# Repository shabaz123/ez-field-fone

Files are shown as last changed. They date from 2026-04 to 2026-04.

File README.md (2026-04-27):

# E-Z Field Fone

This repository contains a project for an intercom / field phone. The design uses discrete components throughout.  

The design includes:
- KiCad 10 Schematic and PCB files
- KiCad 10 SPICE Simulation Workbook
- Gerber files for fabrication  
- PDF schematic export and PCB screenshots for easy viewing without KiCad

# How It Works

The audio input (from on-board mic, or via a handset/earpiece jack socket) is amplified, then sent over bell wire to the remote unit. The signal on the bell wire is fed into a difference amplifier, in order to subtract the local audio. The difference output is fed into a power amplifier. The user can signal a call alert by applying a DC voltage onto the bell wire. There is an amplifier that is sensitive to DC, and the output can be used to light an indicator or sound a buzzer alert.

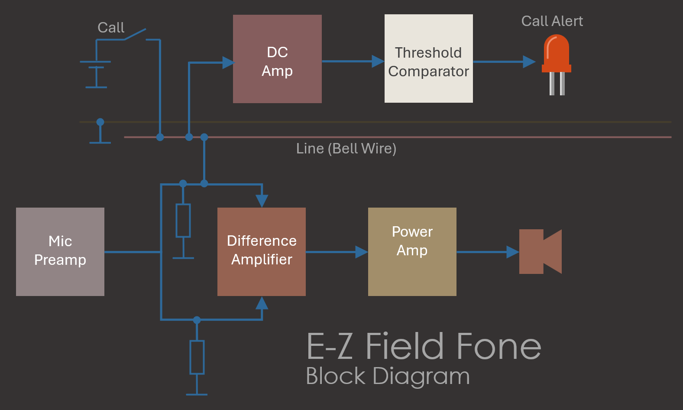
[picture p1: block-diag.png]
Block Diagram


# Printed Circuit Board Overview

The design is split up into two separate printed circuit boards (PCBs). One PCB contains the microphone amplifier (Mic Booard) and the other contains everything else (Main Board). You'll need a mic board, and a main board, for each unit. The two boards are designed to fit into at least a couple of different enclosures. 

# Enclosures

The circuit boards will comfortably fit inside a Hammond 1559E enclosure (170 x 85 x 34 mm) along with a large 60 mm diameter (66 x 66 mm square) 8 ohm speaker such as Pui AS06608PS-R and a PP3 battery. 

If you prefer to omit the speaker and use an external handset, then a smaller Hammond 1593X (140 x 66 x 28 mm) can be used. 

If you wish to use any other enclosure, the PCB dimensions are:

Mic Board: 59 x 32.5 mm

Main Board: 59 x 55 mm

# Mic Board

The mic board uses a preamplifier designed by M. Kellett.

- **Gain:** ~45 dB  
- **Bandwidth (-3 dB):** ~100 Hz to 7 kHz (approximate)

## Schematic

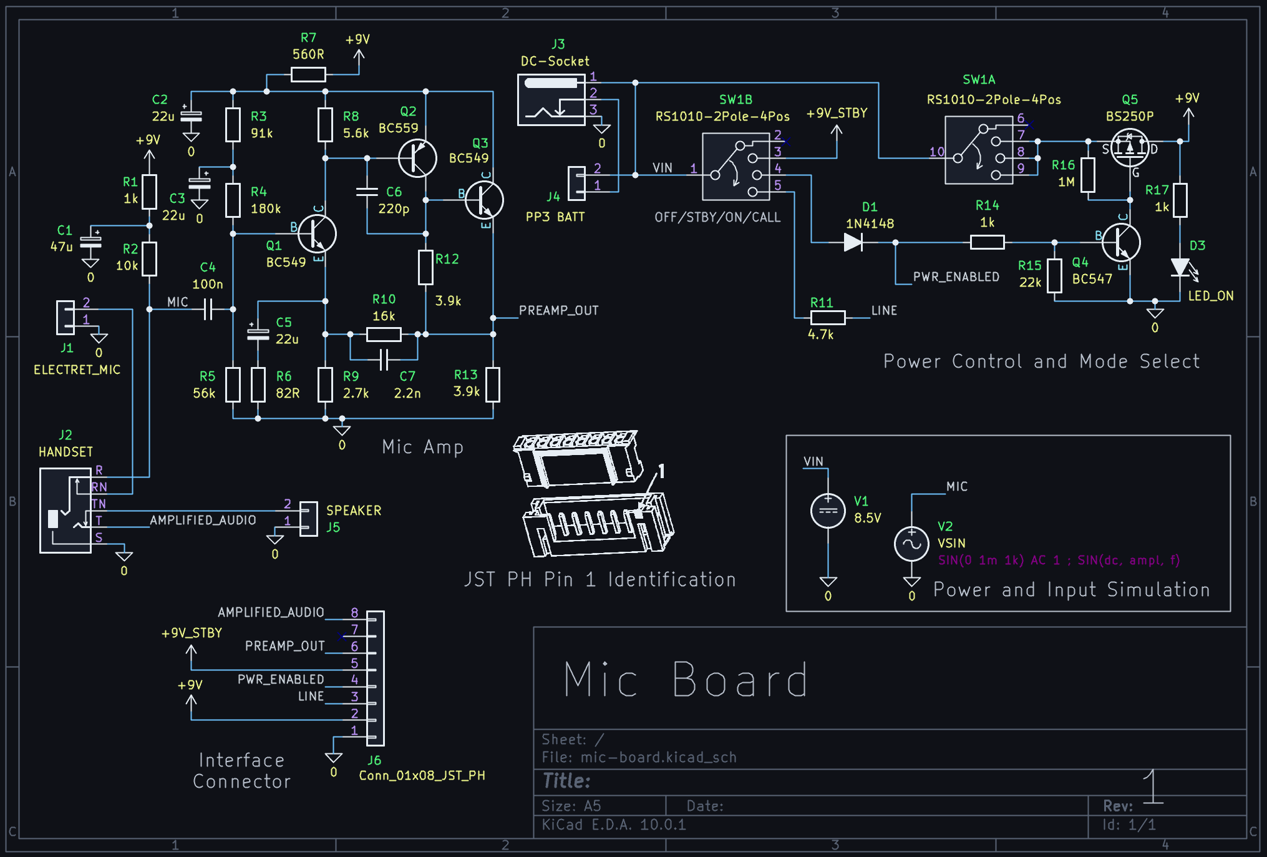
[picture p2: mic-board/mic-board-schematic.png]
Mic Board Schematic


## Board Connections

Two sets of soldered connections need to be made to the Mic Board; the microphone element, and the speaker. Also, an 8-pin connector is used to attach the Mic Board to the Main Board.

### Electret Mic Element

The Mic Board has a 2-pin location for soldering an electret mic element using screened cable

### Speaker

There is a 2-pin location for soldering an 8-ohm speaker

### Interfacing Connector

An 8-pin connector is used to connect a cable between the Mic Board and the Main Board. 

A ready-made JST PH 8-way "opposite direction", also known as "reverse direction" cable can be used (available from AliExpress). The opposite/reverse direction means that when laid flat, opposite sides of the connector are seen from one end to the other (this means that pin 1 of the both connectors are attached to each other, and pin 2 of both connectors are attached to each other, and so on; in contrast, a "same direction" cable has pin 1 on one connector wired to pin 8 of the other connector, and pin 2 to pin 7, and so on). 

Double-check you have the correct cable; do NOT purchase a "same direction" cable!

If you're using the larger Hammond enclosure, the cable length needs to ideally be 15cm (available from a few AliExpress stores) or alternatively 20cm (which more AliExpress stores offer). 

If you're using the smaller Hammond enclosure, a 10cm length cable should reach, but you'll need to measure it or try it out.

## 3.5 mm Audio Jack Pinout

If you wish to plug in an external mic and speaker/eaerphone, use the 3.5 mm 3-pin socket. Connections are:

- Tip: Audio Out, connect this to any earphone or headphones, or to an 8-ohm speaker
- Ring: Microphone, connect this to an electret mic element (the Mic Board PCB supplies a low voltage to power the element)
- Shield: Ground

## PCB Top

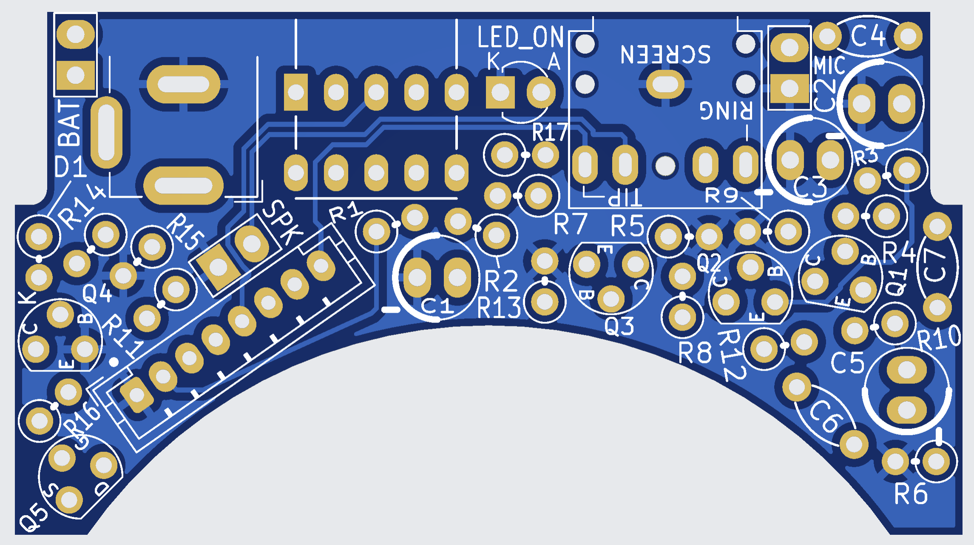
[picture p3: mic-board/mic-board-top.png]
Mic Board Top


## PCB Underside

Note that one wire link needs to be made on the underside; it is labeled on the board.

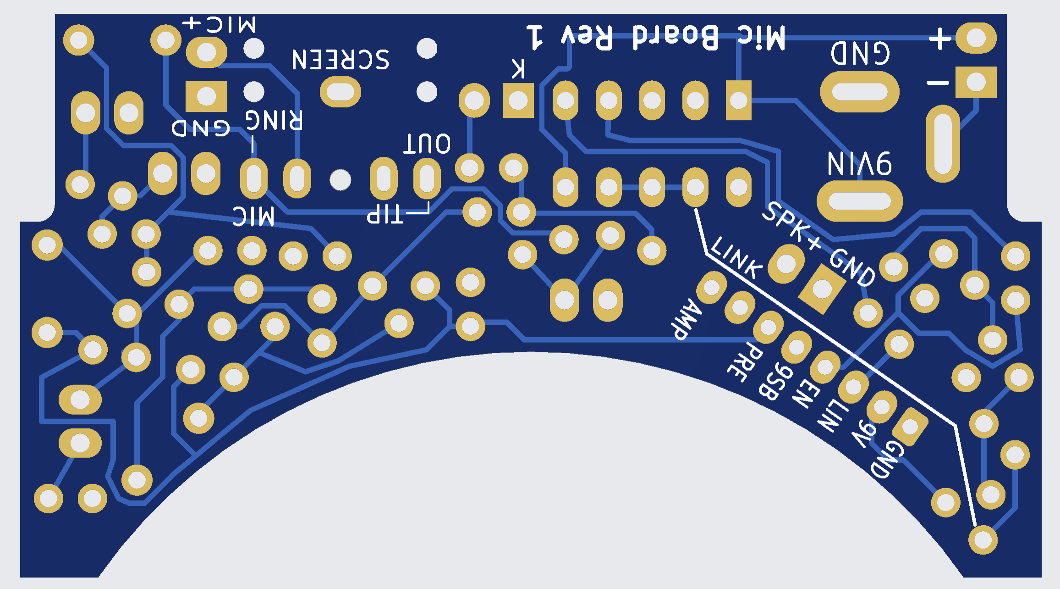
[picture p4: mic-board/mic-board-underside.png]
Mic Board Top


## PCB Render

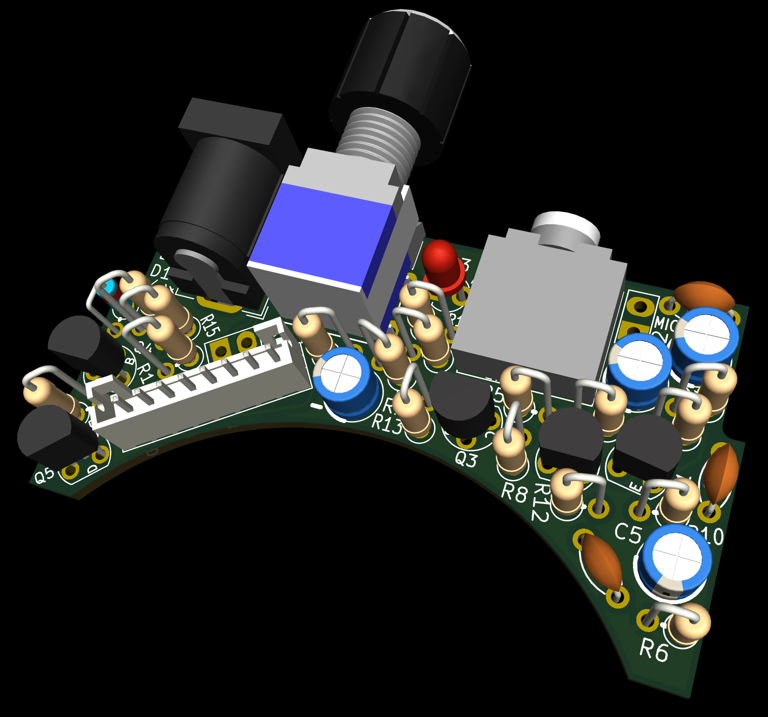
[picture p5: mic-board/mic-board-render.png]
Mic Board Render


## Enclosure Cutouts

The Mic Board requires the following holes to be drilled in the enclosure:

- DC barrel socket
- Rotary switch (4-position, for Off/Standby/On/Call)
- Power ON LED indicator
- 3.5 mm audio socket (for external mic and external earphone/speaker)
- Hole for electret mic element

---

# Main Board

The main board includes a 280mW audio amplifier designed by M. Kellett. 

## Schematic

Note: Resistor R35 is specified to be 630 ohm, this is a hard-to-find value, it may be replaced by 620 ohm in series with 10 ohm (on the PCB, solder 620 ohm and 10 ohm vertically, and connect them at the top with solder).

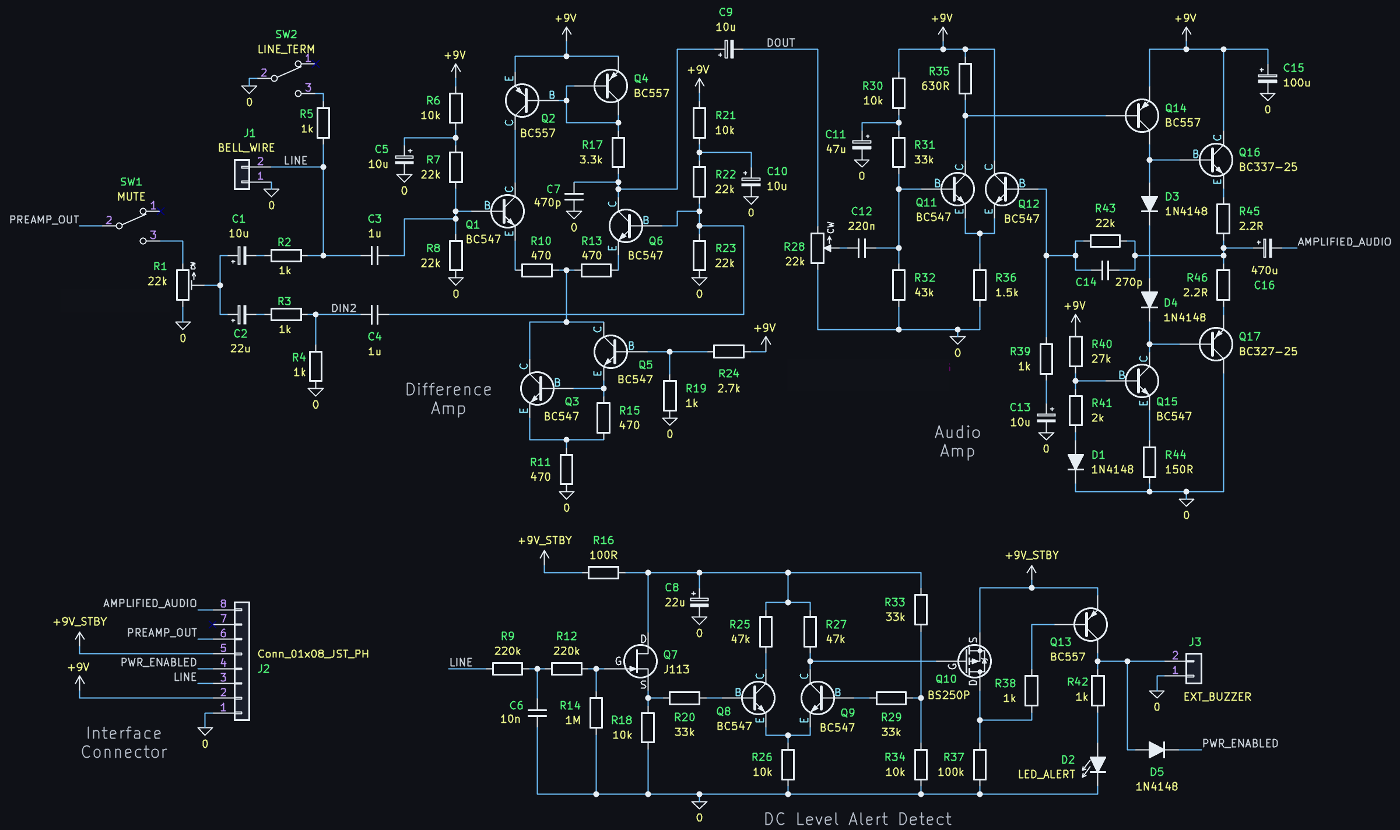
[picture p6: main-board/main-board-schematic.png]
Main Board Schematic


## Board Connections

The only off-board connection from the Main Board is the 8-way connection that interfaces to the Mic Board. See the Mic Board notes earlier, for an explanation of the required cable (8-way JST PH cable, "opposite/reverse direction", i.e. identical pin mapping, pin 1 to pin 1, and pin 2 to pin 2, and so on).

## PCB Top

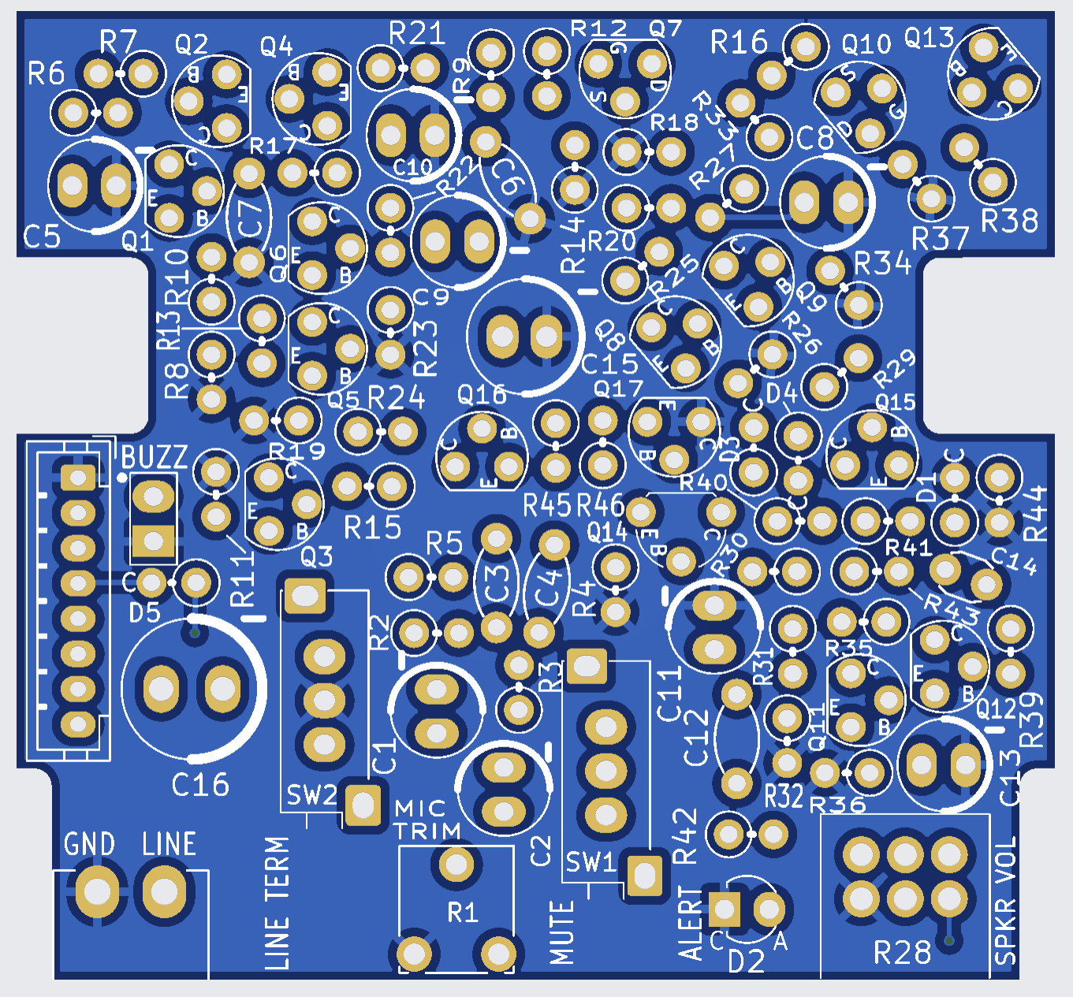
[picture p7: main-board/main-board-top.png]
Main Board Top


## PCB Underside

Note that there are two wire links that need to be soldered on the board underside. The connections are labeled A and B on the circuit board (connect A to A, and connect B to B).

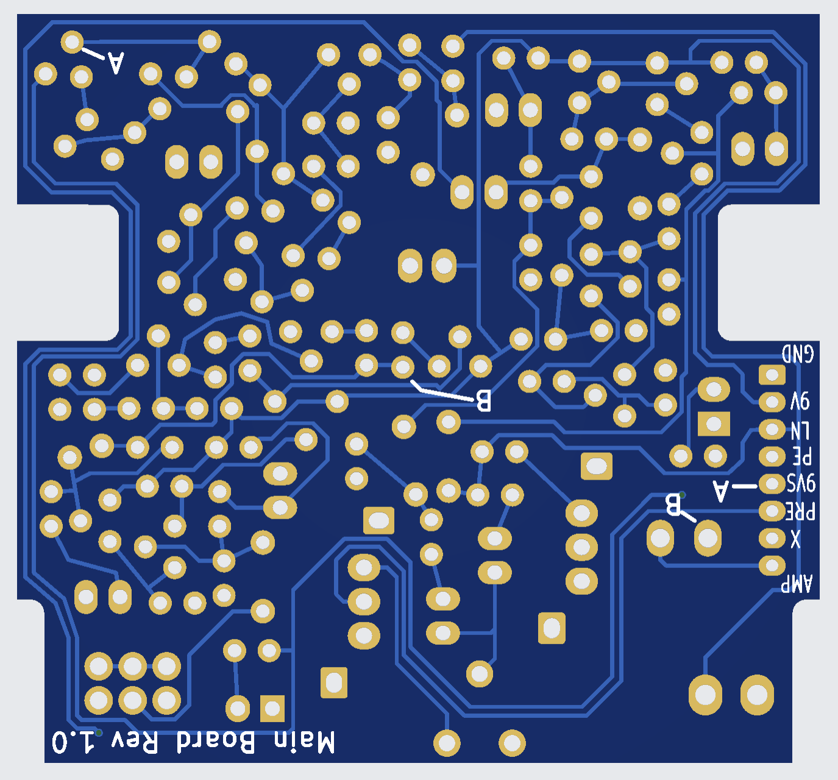
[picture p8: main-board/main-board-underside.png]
Main Board Top


## PCB Render

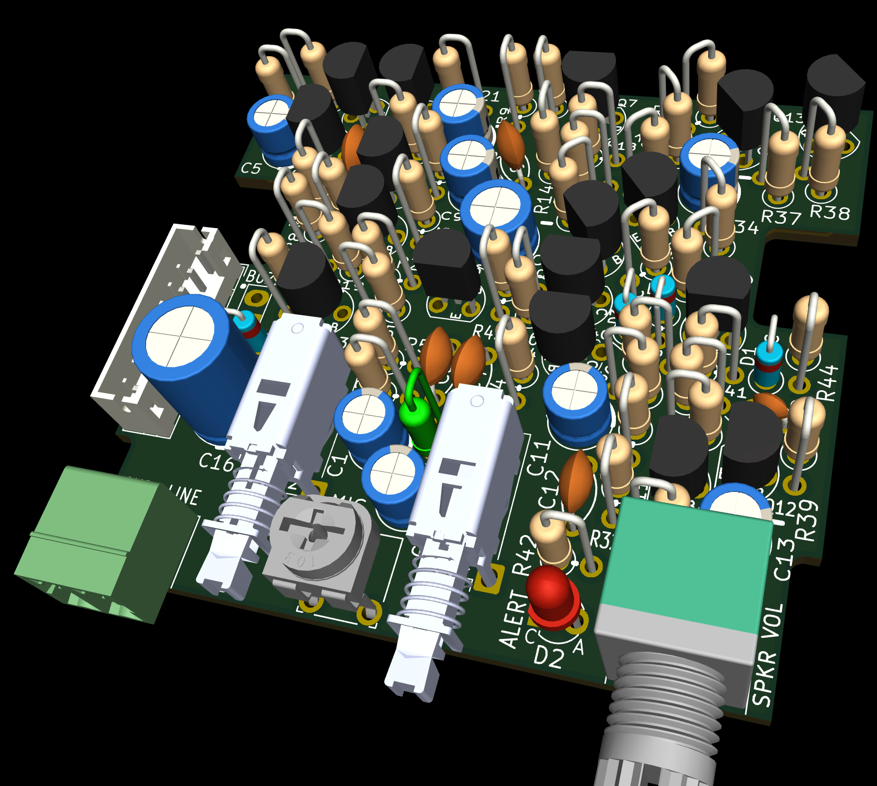
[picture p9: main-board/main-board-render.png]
Main Board Render


## Enclosure Cutouts

The Main Board requires the following holes to be drilled in the enclosure:

- An approximately 9 x 7.5 mm rectangular hole for a 3.81 mm pitch 2-way plug-in terminal block, used for attaching bell wire
- Two approximately 6 mm diameter holes, one for the mute button, and one for the recessed line termination button (the bell wire needs terminating at one end)
- 7.5 mm dia hole for the volume control potentiometer
- Hole for the call alert LED indicator
- Hole for an audio buzzer (if a buzzer is fitted) for audible call alerts

---

## Notes

All components are easy to source. 

For the input power, use a 9V PP3 battery, or use the 9V DC barrel socket (center positive).

The potentiometer can be ALPS RK097 series (available from AliExpress), it has pins at 2.5 mm pitch, and a body width of 10 mm.

The rotary switch is type RS1010 4-way (available from AliExpress)

The push switches can be either PS-12E05, or PN12 series by CK/Littelfuse

For the trimmer resistor, RM065 series will fit the PCB

The line connector (for attaching the bell wire) is a 2-way 3.81 mm pitch terminal block, there are many generic options. One example is WJ15EDGRC-3.81-02P-14-00A (which mates with part code WJ15EDGK-3.81-02P-14-00A

---

# Parts Lists

## Mic Board Parts List

| Reference  | Qty | Value | Description |
| --- | --- | --- | --- |
| C1 | 1 | 47u | Electrolytic Capacitor 5mm dia |
| C2,C3,C5 | 3 | 22u | Electrolytic Capacitor 5mm dia |
| C4 | 1 | 100n | Ceramic Capacitor 5mm pitch |
| C6 | 1 | 220p | Ceramic Capacitor 5mm pitch |
| C7 | 1 | 2.2n | Ceramic Capacitor 5mm pitch |
| D1 | 1 | 1N4148 | Small Signal Diode |
| D3 | 1 | LED_ON | LED 3mm dia |
| J1 | 1 | ELECTRET_MIC | Electret Mic Element |
| J2 | 1 | HANDSET | SJ1-3525N 3.5mm jack CUI |
| J3 | 1 | DC-Socket | 2.1/5.5mm DC Jack Socket |
| J4 | 1 | PP3 BATT | Battery Clip PP3 |
| J5 | 1 | SPEAKER | AS06608PS-R 8-ohm  60mm dia (66 x 66mm) |
| J6 | 1 | B8B-PH-K-S | JST PH Header 8-way Vertical |
| Q1,Q3 | 2 | BC549 | NPN TO-92 Low Noise BJT |
| Q2 | 1 | BC559 | PNP TO-92 Low Noise BJT |
| Q4 | 1 | BC547 | NPN TO-92 BJT |
| Q5 | 1 | BS250P | P-ch MOSFET TO-92 |
| R1,R14,R17 | 3 | 1k | Resistor 1/8W or 1/4W |
| R2 | 1 | 10k | Resistor 1/8W or 1/4W |
| R3 | 1 | 91k | Resistor 1/8W or 1/4W |
| R4 | 1 | 180k | Resistor 1/8W or 1/4W |
| R5 | 1 | 56k | Resistor 1/8W or 1/4W |
| R6 | 1 | 82R | Resistor 1/8W or 1/4W |
| R7 | 1 | 560R | Resistor 1/8W or 1/4W |
| R8 | 1 | 5.6k | Resistor 1/8W or 1/4W |
| R9 | 1 | 2.7k | Resistor 1/8W or 1/4W |
| R10 | 1 | 16k | Resistor 1/8W or 1/4W |
| R11 | 1 | 4.7k | Resistor 1/8W or 1/4W |
| R12,R13 | 2 | 3.9k | Resistor 1/8W or 1/4W |
| R15 | 1 | 22k | Resistor 1/8W or 1/4W |
| R16 | 1 | 1M | Resistor 1/8W or 1/4W |
| SW1 | 1 | RS1010-2Pole-4Pos | 2P4T Rotary Switch |
| n/a | 1 | JST PH 15cm Cable | 8way Opposite/Reverse Direction cable |
| n/a | 1 | Knob 6mm Knurled  | 15mm dia outer, flower inner hole 6mm |

## Main Board Parts List
| Reference | Qty | Value | Description |
| --- | --- | --- | --- |
| C1,C5,C9,C10,C13 | 5 | 10u | Electrolytic Capacitor 5mm dia |
| C2,C8 | 2 | 22u | Electrolytic Capacitor 5mm dia |
| C3,C4 | 2 | 1u | Ceramic Capacitor 5mm pitch |
| C6 | 1 | 10n | Ceramic Capacitor 5mm pitch |
| C7 | 1 | 470p | Ceramic Capacitor 5mm pitch |
| C11 | 1 | 47u | Electrolytic Capacitor 5mm dia |
| C12 | 1 | 220n | Ceramic Capacitor 5mm pitch |
| C14 | 1 | 270p | Ceramic Capacitor 2.5mm pitch |
| C15 | 1 | 100u | Electrolytic Capacitor 6.3mm dia |
| C16 | 1 | 470u | Electrolytic Capacitor 8mm dia |
| D1,D3,D4,D5 | 4 | 1N4148 | Small Signal Diode |
| D2 | 1 | LED_ALERT | LED 3mm dia |
| J1 | 1 | Term Block 3.81mm | 2-way WJ15EDGRC-3.81-02P-14-00A |
| J2 | 1 | B8B-PH-K-S | JST PH Header 8-way Vertical |
| J3 | 1 | EXT_BUZZER | 9V Buzzer (optional) |
| Q1,Q3,Q5,Q6,Q8,Q9,Q11,Q12,Q15 | 9 | BC547 | NPN TO-92 BJT |
| Q2,Q4,Q13,Q14 | 4 | BC557 | PNP TO-92 BJT |
| Q7 | 1 | J113 | N-ch JFET TO-92 |
| Q10 | 1 | BS250P | P-ch MOSFET TO-92 |
| Q16 | 1 | BC337-25 | NPN TO-92 Power BJT |
| Q17 | 1 | BC327-25 | PNP TO-92 Power BJT |
| R1 | 1 | 22k | RM065 Trimmer Potentiometer |
| R2,R3,R4,R5,R19,R38,R39,R42 | 8 | 1k | Resistor 1/8W or 1/4W |
| R6,R18,R21,R26,R30,R34 | 6 | 10k | Resistor 1/8W or 1/4W |
| R7,R8,R22,R23,R43 | 5 | 22k | Resistor 1/8W or 1/4W |
| R9,R12 | 2 | 220k | Resistor 1/8W or 1/4W |
| R10,R11,R13,R15 | 4 | 470R | Resistor 1/8W or 1/4W |
| R14 | 1 | 1M | Resistor 1/8W or 1/4W |
| R16 | 1 | 100R | Resistor 1/8W or 1/4W |
| R17 | 1 | 3.3k | Resistor 1/8W or 1/4W |
| R20,R29,R31,R33 | 4 | 33k | Resistor 1/8W or 1/4W |
| R24 | 1 | 2.7k | Resistor 1/8W or 1/4W |
| R25,R27 | 2 | 47k | Resistor 1/8W or 1/4W |
| R28 | 1 | 22k | Resistor 1/8W or 1/4W |
| R32 | 1 | 43k | Resistor 1/8W or 1/4W |
| R35 | 1 | 630R (620R+10R) | Resistor 1/8W or 1/4W |
| R36 | 1 | 1.5k | Resistor 1/8W or 1/4W |
| R37 | 1 | 100k | Resistor 1/8W or 1/4W |
| R40 | 1 | 27k | Resistor 1/8W or 1/4W |
| R41 | 1 | 2k | Resistor 1/8W or 1/4W |
| R44 | 1 | 150R | Resistor 1/8W or 1/4W |
| R45,R46 | 2 | 2.2R | Resistor 1/4W |
| SW1 | 1 | PS-12E05 | SPDT Switch Latching PN12 |
| SW2 | 1 | PS-12E05 | SPDT Switch Latching PN12 |
| n/a | 1 | Plug 3.81mm | 2-way WJ15EDGK-3.81-02P-14-00A |
| n/a | 1 | Knob 6mm Knurled  | 15mm dia outer, flower inner hole 6mm |

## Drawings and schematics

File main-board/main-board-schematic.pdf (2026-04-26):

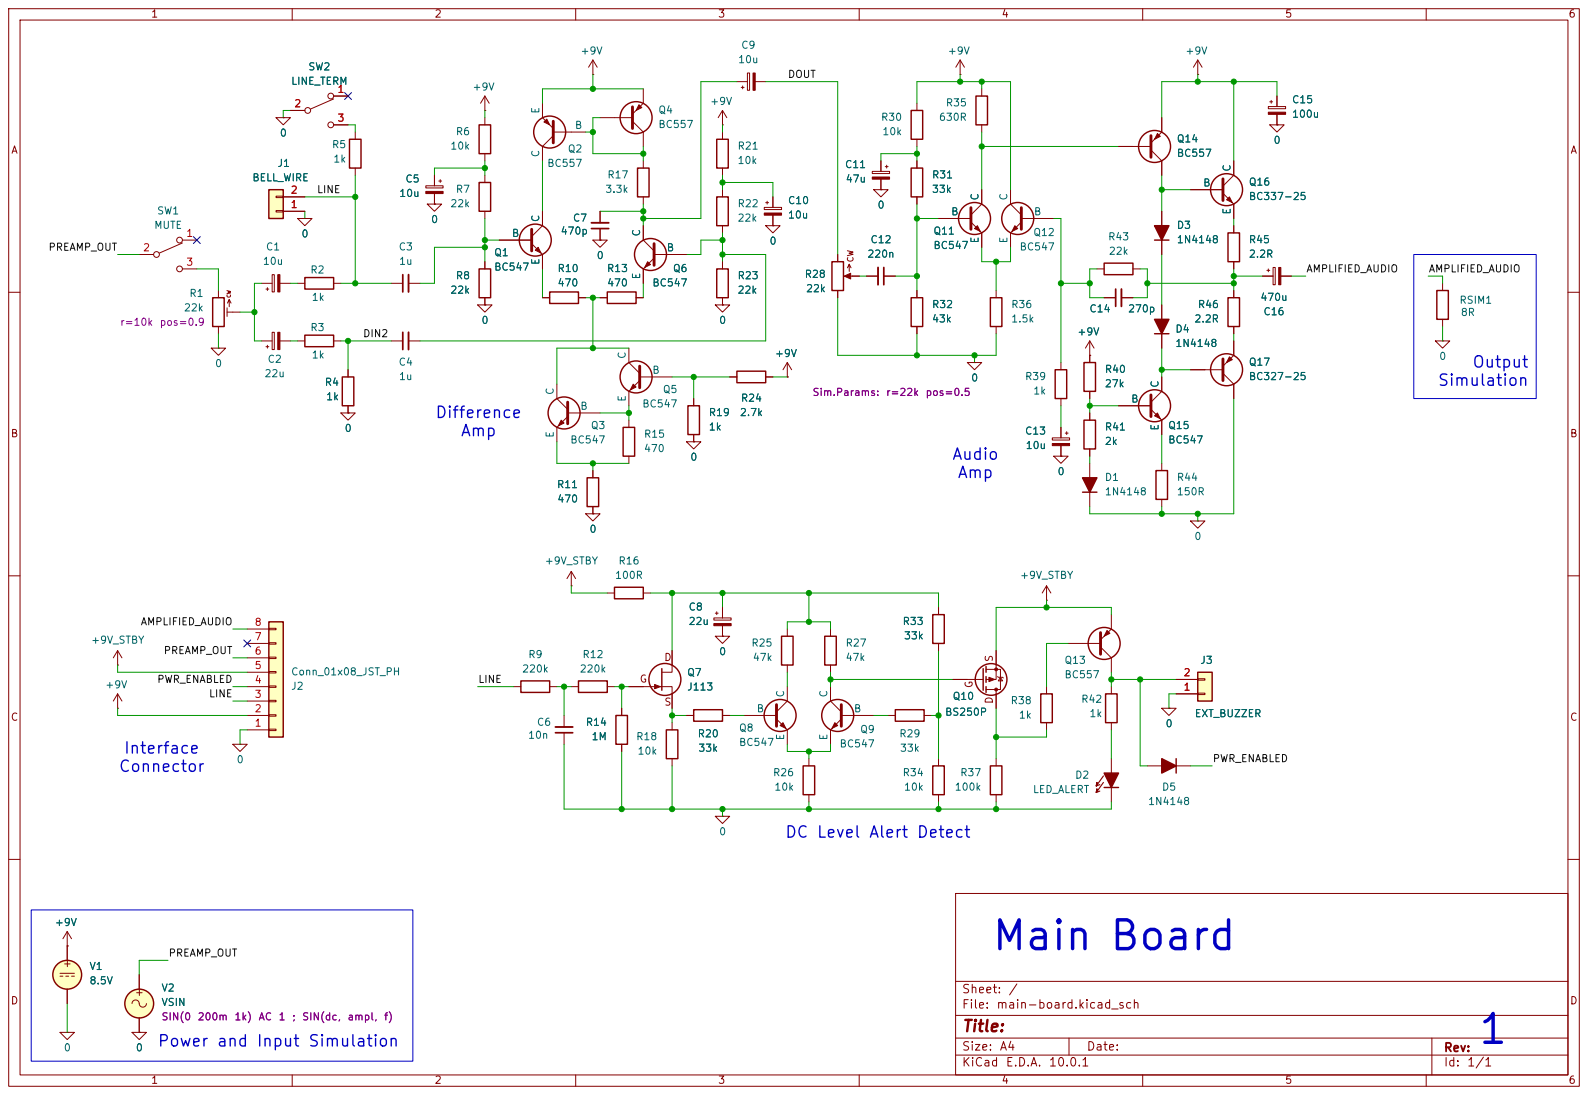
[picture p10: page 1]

AMPLIFIED_AUDIO Power and Input Simulation

DC Level Alert Detect

SIN(0 200m 1k) AC 1 ; SIN(dc, ampl, f) V1

Size: A4 | Rev:
KiCad E.D.A. 10.0.1 | Id: 1/1

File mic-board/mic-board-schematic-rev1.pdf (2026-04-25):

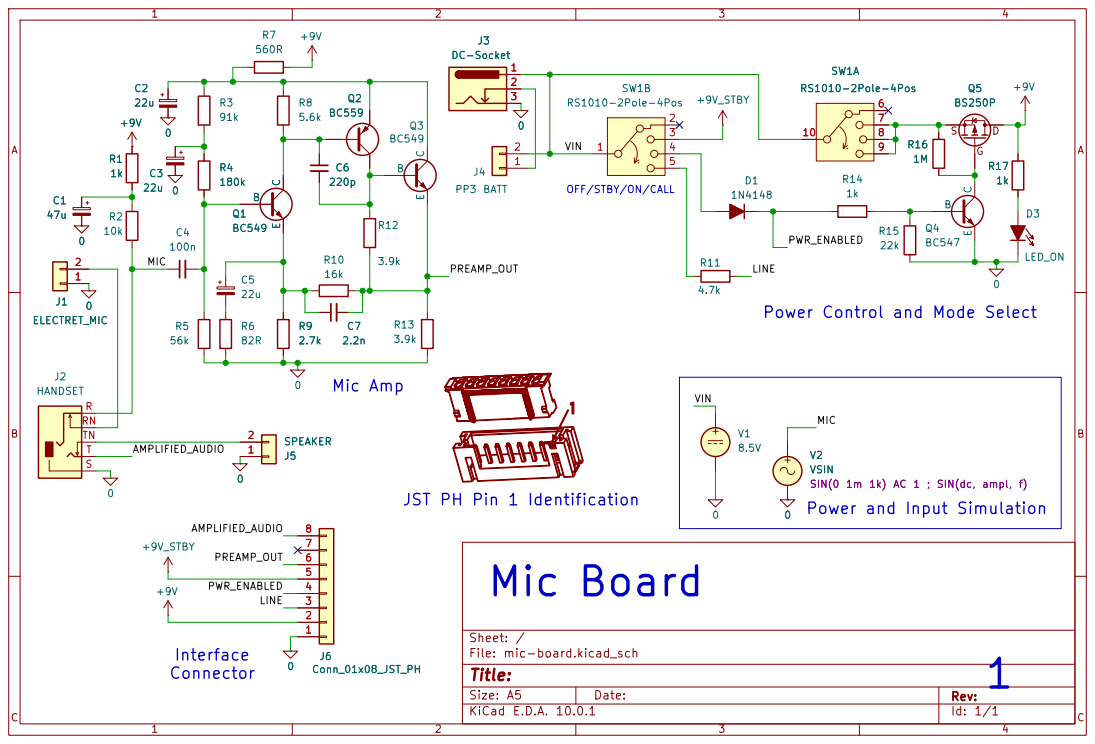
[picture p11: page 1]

Power Control and Mode Select SW1A RS1010-2Pole-4Pos 6

SIN(0 1m 1k) AC 1 ; SIN(dc, ampl, f) 0 Q1BC549 C

OFF/STBY/ON/CALL

VSIN
SIN(0 1m 1k) AC 1 ; SIN(dc, ampl, f) 0
Power and Input Simulation

JST PH Pin 1 Identification

Size: A5 | Rev: | C Date:
KiCad E.D.A. 10.0.1 | Id: 1/1

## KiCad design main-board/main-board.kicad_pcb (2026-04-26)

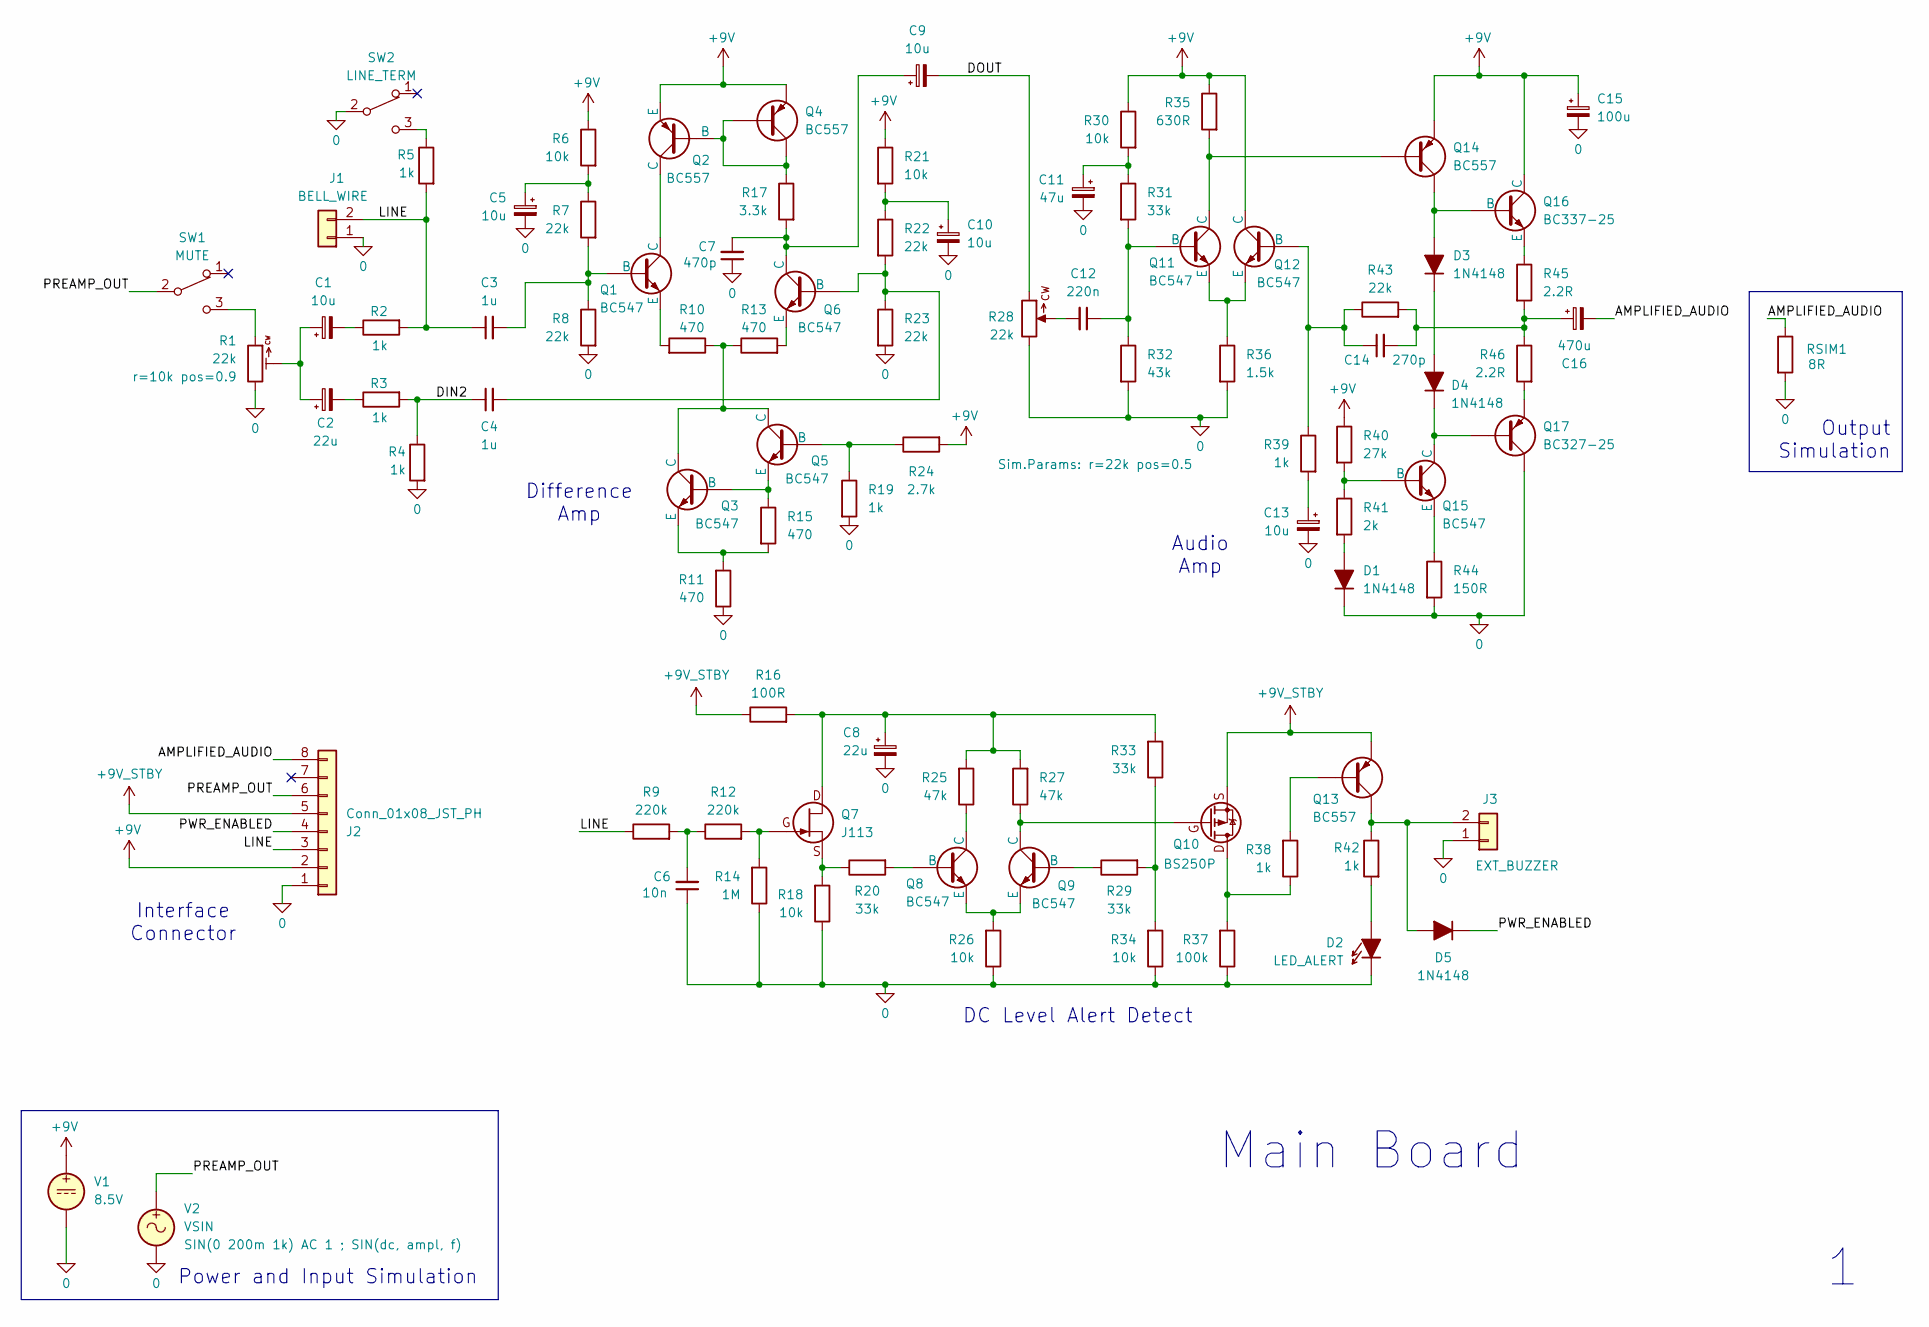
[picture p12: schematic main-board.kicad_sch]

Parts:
C1, C5, C9, C10, C13: 10u; CP_Radial_D5.0mm_P2.50mm
C2, C8: 22u; CP_Radial_D5.0mm_P2.50mm
C3, C4: 1u; C_Disc_T3.0mm_P5.0
C6: 10n; C_Disc_T3.0mm_P5.0
C7: 470p; C_Disc_T3.0mm_P5.0
C11: 47u; CP_Radial_D5.0mm_P2.50mm
C12: 220n; C_Disc_T3.0mm_P5.0
C14: 270p; C_Disc_T2.5mm_P2.5
C15: 100u; CP_Radial_D6.3mm_P2.50mm
C16: 470u; CP_Radial_D8mm_P3.5mm
D1, D3, D4, D5: 1N4148; D_DO-35_P2.54mm_Vertical_CathodeUp
D2: LED_ALERT; LED_3mm
J1: BELL_WIRE; TerminalBlock_RightAngle-2way-3.81mm
J2: Conn_01x08_JST_PH; JST_PH_Vertical_8way
J3: EXT_BUZZER; PinHeader_1x02_P2.54mm_Vertical
Q1, Q3, Q5, Q8, Q9, Q11, Q12, Q15: BC547; BJT_NPN_BC547_Compact
Q2, Q4, Q13: BC557; BJT_PNP_BC557_Compact
Q6: BC547; BJT_PNP_BC557_Compact
Q7: J113; J113_NCH_JFET_Compact
Q10: BS250P; MOSFET_BS250P_Compact
Q14: BC557; BJT_PNP_BC557_Compact2
Q16: BC337-25; BJT_NPN_BC547_Compact
Q17: BC327-25; BJT_PNP_BC557_Compact
R1: 22k; Potentiometer_Trimmer_RM065
R2, R3, R4, R5, R19, R38, R39, R42: 1k; R_Axial_L6.3mm_D2.5mm_P2.54mm_Vertical
R6, R18, R21, R26, R30, R34: 10k; R_Axial_L6.3mm_D2.5mm_P2.54mm_Vertical
R7, R8, R22, R23, R43: 22k; R_Axial_L6.3mm_D2.5mm_P2.54mm_Vertical
R9, R12: 220k; R_Axial_L6.3mm_D2.5mm_P2.54mm_Vertical
R10, R11, R13, R15: 470; R_Axial_L6.3mm_D2.5mm_P2.54mm_Vertical
R14: 1M; R_Axial_L6.3mm_D2.5mm_P2.54mm_Vertical
R16: 100R; R_Axial_L6.3mm_D2.5mm_P2.54mm_Vertical
R17: 3.3k; R_Axial_L6.3mm_D2.5mm_P2.54mm_Vertical
R20, R29, R31, R33: 33k; R_Axial_L6.3mm_D2.5mm_P2.54mm_Vertical
R24: 2.7k; R_Axial_L6.3mm_D2.5mm_P2.54mm_Vertical
R25, R27: 47k; R_Axial_L6.3mm_D2.5mm_P2.54mm_Vertical
R28: 22k; Potentiometer_RD701F
R32: 43k; R_Axial_L6.3mm_D2.5mm_P2.54mm_Vertical
R35: 630R; R_Axial_L6.3mm_D2.5mm_P2.54mm_Vertical
R36: 1.5k; R_Axial_L6.3mm_D2.5mm_P2.54mm_Vertical
R37: 100k; R_Axial_L6.3mm_D2.5mm_P2.54mm_Vertical
R40: 27k; R_Axial_L6.3mm_D2.5mm_P2.54mm_Vertical
R41: 2k; R_Axial_L6.3mm_D2.5mm_P2.54mm_Vertical
R44: 150R; R_Axial_L6.3mm_D2.5mm_P2.54mm_Vertical
R45, R46: 2.2R; R_Axial_L6.3mm_D2.5mm_P2.54mm_Vertical
RSIM1: 8R; R_Axial_L6.3mm_D2.5mm_P10.16mm_Horiz
SW1: MUTE; PS-12E05
SW2: LINE_TERM; PS-12E05
V1: 8.5V
V2: VSIN

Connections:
0: C5.2, C6.1, C7.1, C8.2, C10.2, C11.2, C13.2, C15.2, D1.1 (K), D2.1 (K), J1.1, J2.1, J3.1, Q17.1 (C), R1.1, R4.2, R8.2, R11.1, R14.1, R18.1, R19.2, R23.2, R26.1, R28.1, R32.2, R34.1, R36.2, R37.1, R44.2, RSIM1.2, SW2.2 (B), V1.2, V2.2
+9V: C15.1, J2.2, Q2.3 (E), Q4.3 (E), Q12.1 (C), Q14.3 (E), Q16.1 (C), R6.1, R21.1, R24.2, R30.1, R35.1, R40.1, V1.1
+9V_STBY: J2.5, Q10.1 (S), Q13.3 (E), R16.1
/AMPLIFIED_AUDIO: C16.2, J2.8, RSIM1.1
/DIN2: C4.1, R3.2, R4.1
/DOUT: C9.2, R28.3
/LINE: C3.1, J1.2, J2.3, R2.2, R5.2, R9.1
/PREAMP_OUT: J2.6, SW1.2 (B), V2.1
/PWR_ENABLED: D5.1 (K), J2.4
unnamed: C1.1, C2.1, R1.2
unnamed: C1.2, R2.1
unnamed: C2.2, R3.1
unnamed: C5.1, R6.2, R7.1
unnamed: C6.2, R9.2, R12.1
unnamed: C10.1, R21.2, R22.1
unnamed: C11.1, R30.2, R31.1
unnamed: C12.2, R28.2
unnamed: C13.1, R39.2
unnamed: C14.2, C16.1, R43.2, R45.2, R46.1
unnamed: D1.2 (A), R41.2
unnamed: D2.2 (A), R42.2
unnamed: D3.2 (A), Q14.1 (C), Q16.2 (B)
unnamed: D3.1 (K), D4.2 (A)
unnamed: D4.1 (K), Q15.1 (C), Q17.2 (B)
unnamed: D5.2 (A), J3.2, Q13.1 (C), R42.1
unnamed: C3.2, Q1.2 (B), R7.2, R8.1
unnamed: Q1.1 (C), Q2.1 (C)
unnamed: Q1.3 (E), R10.2
unnamed: Q2.2 (B), Q4.1 (C), Q4.2 (B), R17.1
unnamed: Q3.2 (B), Q5.3 (E), R15.1
unnamed: Q3.1 (C), Q5.1 (C), R10.1, R13.1
unnamed: Q3.3 (E), R11.2, R15.2
unnamed: Q5.2 (B), R19.1, R24.1
unnamed: C4.2, Q6.2 (B), R22.2, R23.1
unnamed: C7.2, C9.1, Q6.1 (C), R17.2
unnamed: Q6.3 (E), R13.2
unnamed: C8.1, Q7.1 (D), R16.2, R25.2, R27.2, R33.2
unnamed: Q7.3 (G), R12.2, R14.2
unnamed: Q7.2 (S), R18.2, R20.1
unnamed: Q8.2 (B), R20.2
unnamed: Q8.1 (C), R25.1
unnamed: Q8.3 (E), Q9.3 (E), R26.2
unnamed: Q9.2 (B), R29.1
unnamed: Q10.3 (D), R37.2, R38.1
unnamed: Q9.1 (C), Q10.2 (G), R27.1
unnamed: C12.1, Q11.2 (B), R31.2, R32.1
unnamed: Q11.1 (C), Q14.2 (B), R35.2
unnamed: Q11.3 (E), Q12.3 (E), R36.1
unnamed: C14.1, Q12.2 (B), R39.1, R43.1
unnamed: Q13.2 (B), R38.2
unnamed: Q15.2 (B), R40.2, R41.1
unnamed: Q15.3 (E), R44.1
unnamed: Q16.3 (E), R45.1
unnamed: Q17.3 (E), R46.2
unnamed: R29.2, R33.1, R34.2
unnamed: R1.3, SW1.3 (C)
unnamed: R5.1, SW2.3 (C)

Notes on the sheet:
Power and Input Simulation
Output Simulation
DC Level Alert Detect
Interface Connector
Difference Amp
Audio Amp
Main Board

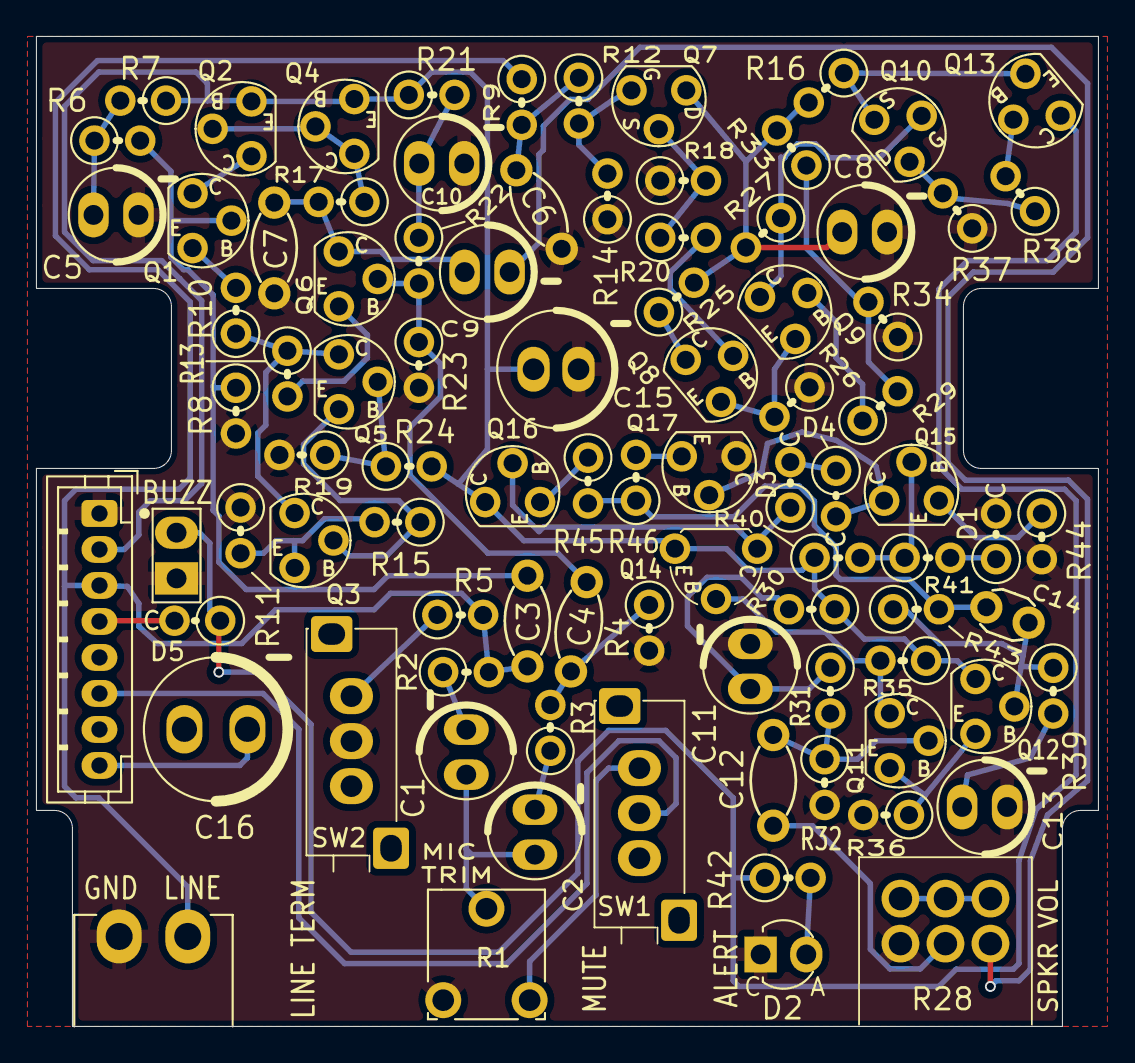
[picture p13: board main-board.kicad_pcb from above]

Board: 2 copper layers, 59.0 x 55.0 mm, 89 parts (0 on the bottom side), 57 nets.

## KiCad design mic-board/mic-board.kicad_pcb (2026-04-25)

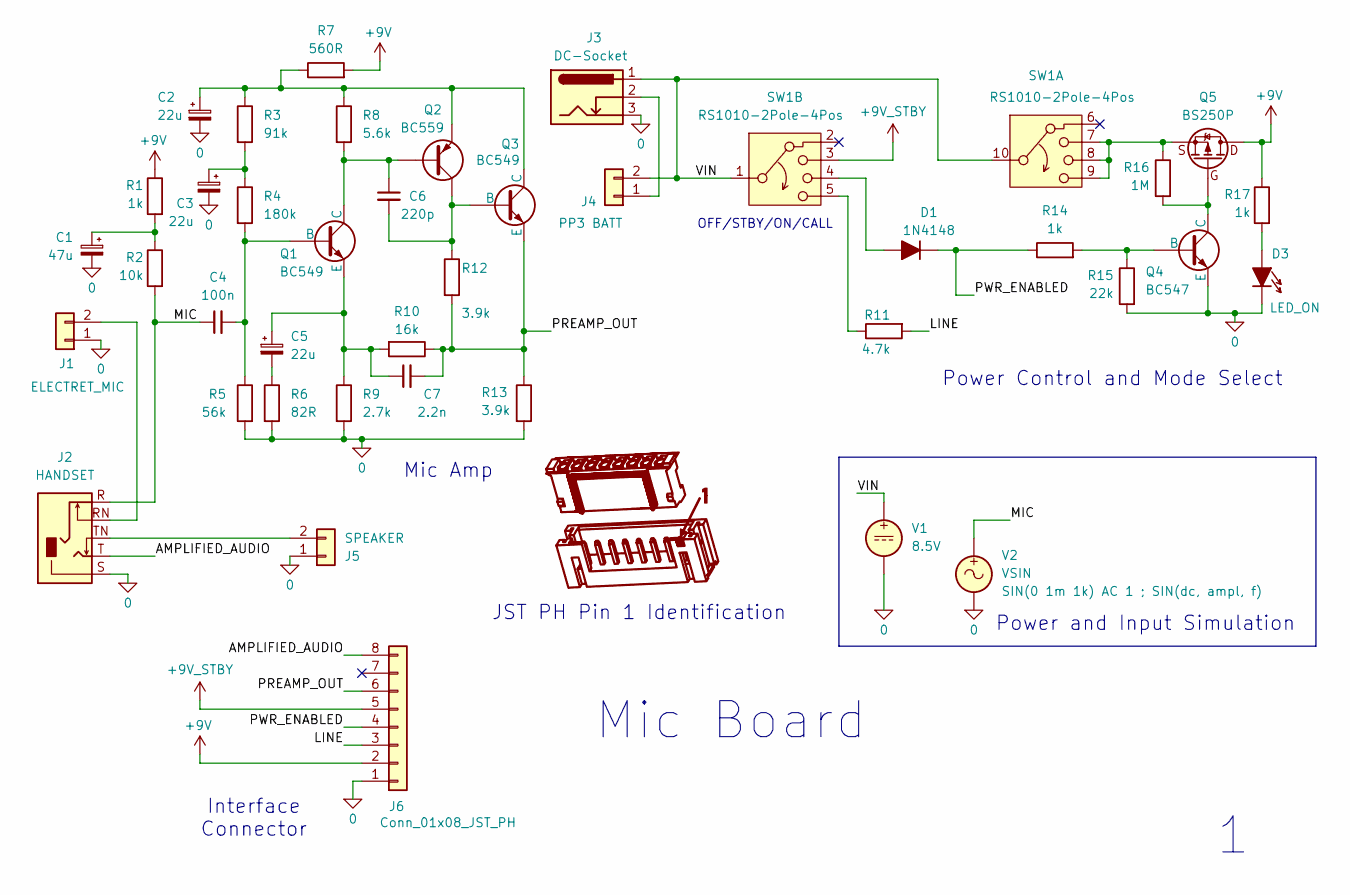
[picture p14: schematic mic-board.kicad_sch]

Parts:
C1: 47u; CP_Radial_D5.0mm_P2.50mm
C2, C3, C5: 22u; CP_Radial_D5.0mm_P2.50mm
C4: 100n; C_Disc_T3.0mm_P5.0
C6: 220p; C_Disc_T3.0mm_P5.0
C7: 2.2n; C_Disc_T3.0mm_P5.0
D1: 1N4148; D_DO-35_P2.54mm_Vertical_CathodeUp
D3: LED_ON; LED_3mm
J1: ELECTRET_MIC; PinHeader_1x02_P2.54mm_Vertical
J2: HANDSET; Jack_3.5mm_CUI_SJ1-3525N_Horizontal2
J3: DC-Socket; DC-Jack-10-extra-reduced-silk
J4: PP3 BATT; PinHeader_1x02_P2.54mm_Vertical
J5: SPEAKER; PinHeader_1x02_P2.54mm_Vertical
J6: Conn_01x08_JST_PH; JST_PH_Vertical_8way
Q1, Q3: BC549; BJT_NPN_BC547_Compact
Q2: BC559; BJT_PNP_BC557_Compact
Q4: BC547; BJT_NPN_BC547_Compact
Q5: BS250P; MOSFET_BS250P_Compact
R1, R14, R17: 1k; R_Axial_L6.3mm_D2.5mm_P2.54mm_Vertical
R2: 10k; R_Axial_L6.3mm_D2.5mm_P2.54mm_Vertical
R3: 91k; R_Axial_L6.3mm_D2.5mm_P2.54mm_Vertical
R4: 180k; R_Axial_L6.3mm_D2.5mm_P2.54mm_Vertical
R5: 56k; R_Axial_L6.3mm_D2.5mm_P2.54mm_Vertical
R6: 82R; R_Axial_L6.3mm_D2.5mm_P2.54mm_Vertical
R7: 560R; R_Axial_L6.3mm_D2.5mm_P2.54mm_Vertical
R8: 5.6k; R_Axial_L6.3mm_D2.5mm_P2.54mm_Vertical
R9: 2.7k; R_Axial_L6.3mm_D2.5mm_P2.54mm_Vertical
R10: 16k; R_Axial_L6.3mm_D2.5mm_P2.54mm_Vertical
R11: 4.7k; R_Axial_L6.3mm_D2.5mm_P2.54mm_Vertical
R12, R13: 3.9k; R_Axial_L6.3mm_D2.5mm_P2.54mm_Vertical
R15: 22k; R_Axial_L6.3mm_D2.5mm_P2.54mm_Vertical
R16: 1M; R_Axial_L6.3mm_D2.5mm_P2.54mm_Vertical
SW1: RS1010-2Pole-4Pos; RS1010
V1: 8.5V
V2: VSIN

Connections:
0: C1.2, C2.2, C3.2, D3.1 (K), J1.1, J2.S, J3.3, J5.1, J6.1, Q4.3 (E), R5.2, R6.2, R9.2, R13.2, R15.2, V1.2, V2.2
+9V: J6.2, Q5.3 (D), R1.1, R7.2, R17.1
+9V_STBY: J6.5, SW1.3
/AMPLIFIED_AUDIO: J2.T, J6.8
/LINE: J6.3, R11.2
/MIC: C4.1, J2.R, R2.2, V2.1
/PREAMP_OUT: C7.2, J6.6, Q3.3 (E), R10.1, R12.2, R13.1
/PWR_ENABLED: D1.1 (K), J6.4, R14.1
/VIN: J3.1, J4.2, SW1.1, SW1.10, V1.1
unnamed: C1.1, R1.2, R2.1
unnamed: C3.1, R3.2, R4.1
unnamed: C5.2, R6.1
unnamed: D1.2 (A), SW1.4
unnamed: D3.2 (A), R17.2
unnamed: J1.2, J2.RN
unnamed: J3.2, J4.1
unnamed: J2.TN, J5.2
unnamed: C4.2, Q1.2 (B), R4.2, R5.1
unnamed: C6.1, Q1.1 (C), Q2.2 (B), R8.2
unnamed: C5.1, C7.1, Q1.3 (E), R9.1, R10.2
unnamed: C6.2, Q2.1 (C), Q3.2 (B), R12.1
unnamed: C2.1, Q2.3 (E), Q3.1 (C), R3.1, R7.1, R8.1
unnamed: Q4.2 (B), R14.2, R15.1
unnamed: Q4.1 (C), Q5.2 (G), R16.2
unnamed: Q5.1 (S), R16.1, SW1.7, SW1.8, SW1.9
unnamed: R11.1, SW1.5

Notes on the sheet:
Power and Input Simulation
OFF/STBY/ON/CALL
JST PH Pin 1 Identification
Interface Connector
Mic Amp
Power Control and Mode Select
Mic Board

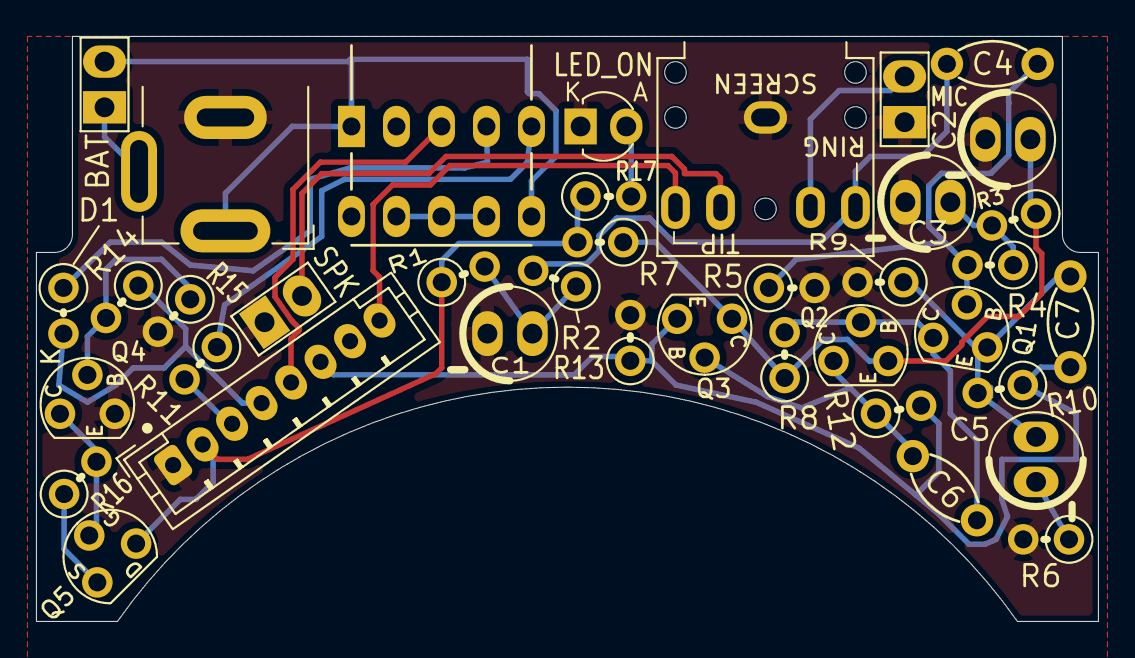
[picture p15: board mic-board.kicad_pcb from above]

Board: 2 copper layers, 59.0 x 32.5 mm, 38 parts (0 on the bottom side), 26 nets.

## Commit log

2026-04-26 Add enclosure cutouts section to README
    Added details about enclosure cutouts required for the Main Board.
2026-04-27 Add parts lists for Mic and Main Boards
    Added detailed parts lists for Mic Board and Main Board.
2026-04-27 Update R35 resistor description in README
2026-04-27 Update resistor R35 replacement instructions
    Clarified instructions for replacing resistor R35 in the schematic section.
2026-04-27 Clarify cable direction terminology in README
